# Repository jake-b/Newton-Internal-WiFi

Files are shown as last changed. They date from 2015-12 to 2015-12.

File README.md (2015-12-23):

# Newton-Internal-WiFi
Design and software for a WiFi board for the Apple Newton MessagePad 2x00

- The PCB design for the board (v1.1)
- The Newton PKG software module for enabling the board in software
- STL files for 3D printing a replacement modem port cover. The original
  port cover interferes with the installed PCB.  I have also included a
  representation of the original port cover, in case you need one.  There
  is a version with supports for printing on a typical hobbiest 
  fused-filament 3D printer.  Trim carefully to size using a razor blade.

# Bill of Materials

- PCB fabricated to 0.8mm thickness
- IW-SMG2SMT-EX - Wireach WiFi / 802.11 Module - External Antenna
- JAE IL-WX-32PB-VF-BE - Internal Connector - No longer available
- LMZ21700SILT - Voltage Regulator Module
- R1 SMD 0603 15k Resistor
- Cout SMD 0805 22uF Capacitor
- Cin, C3 SMD 0805 10uF Capacitor
- Css SMD 0603 3.3nF Capacitor
- C4 SMD 0805 470nF
- Rt SMD 0603 562K ohm 1% Resistor
- Rb SMD 0603 180Kohm 0.5% Resistor
- MC74VHCT50ADT - Buffer
- MC74VHC1G04DFT2G - 1G Inverter
- Resettable Fuses - PPTC 15V 1206 .500A POLYFUSE

# License & Disclaimer
This project is released under the Attribution-NonCommercial-ShareAlike 4.0 
International license.

- Feel free to make your own, or make one for your friends.
- Please release any improvements back to the community.
- Non-commerical use only. Please don't make & sell these at a profit.  If
  by some odd chance you want to make these for sale, please contact me.

As with all of my projects, please use this at your own risk.

BECAUSE THE PROGRAM & HARDWARE DESIGN IS LICENSED FREE OF CHARGE, THERE IS NO 
WARRANTY FOR THE PROGRAM & HARDWARE DESIGN, TO THE EXTENT PERMITTED BY 
APPLICABLE LAW. EXCEPT WHEN OTHERWISE STATED IN WRITING THE COPYRIGHT HOLDERS 
AND/OR OTHER PARTIES PROVIDE THE PROGRAM & HARDWARE DESIGN "AS IS" WITHOUT 
WARRANTY OF ANY KIND, EITHER EXPRESSED OR IMPLIED, INCLUDING, BUT NOT LIMITED 
TO, THE IMPLIED WARRANTIES OF MERCHANTABILITY AND FITNESS FOR A PARTICULAR 
PURPOSE. THE ENTIRE RISK AS TO THE QUALITY AND PERFORMANCE OF THE PROGRAM &
HARDWARE DESIGN IS WITH YOU. SHOULD THE PROGRAM OR HARDWARE DESIGN PROVE 
DEFECTIVE, YOU ASSUME THE COST OF ALL NECESSARY SERVICING, REPAIR OR CORRECTION.

IN NO EVENT UNLESS REQUIRED BY APPLICABLE LAW OR AGREED TO IN WRITING WILL ANY
COPYRIGHT HOLDER, OR ANY OTHER PARTY WHO MAY MODIFY AND/OR REDISTRIBUTE THE 
PROGRAM OR HARDWARE DESIGN AS PERMITTED ABOVE, BE LIABLE TO YOU FOR DAMAGES, 
INCLUDING ANY GENERAL,  SPECIAL, INCIDENTAL OR CONSEQUENTIAL DAMAGES ARISING 
OUT OF THE USE OR INABILITY TO USE THE PROGRAM OR HARDWARE DESIGN (INCLUDING 
BUT NOT LIMITED TO LOSS OF DATA OR DATA BEING RENDERED INACCURATE OR LOSSES 
SUSTAINED BY YOU OR THIRD PARTIES OR A FAILURE OF THE PROGRAM OR HARDWARE 
DESIGN TO OPERATE WITH ANY OTHER PROGRAMS OR HARDWARE), EVEN IF SUCH HOLDER 
OR OTHER PARTY HAS BEEN ADVISED OF THE POSSIBILITY OF SUCH DAMAGES.

The software included toggles low level hardware signals using undocumented 
Newton ROM functions. It is intended for developer use. You should know what 
you're doing, as this could do damage to your hardware.

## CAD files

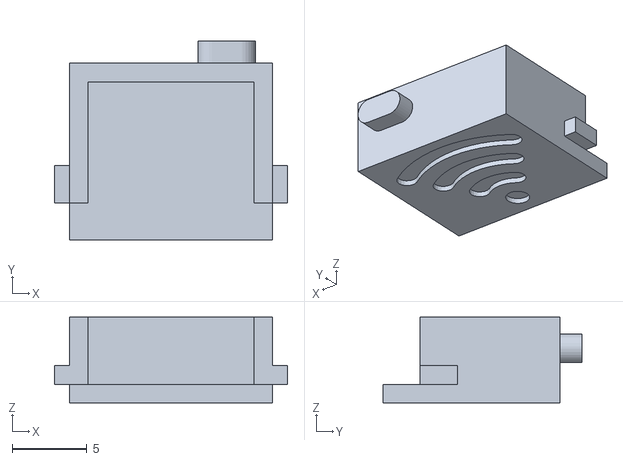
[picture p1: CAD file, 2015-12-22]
Port Cover/Wifi Modem Port Cover.stl
15.6 x 13.4 x 5.75

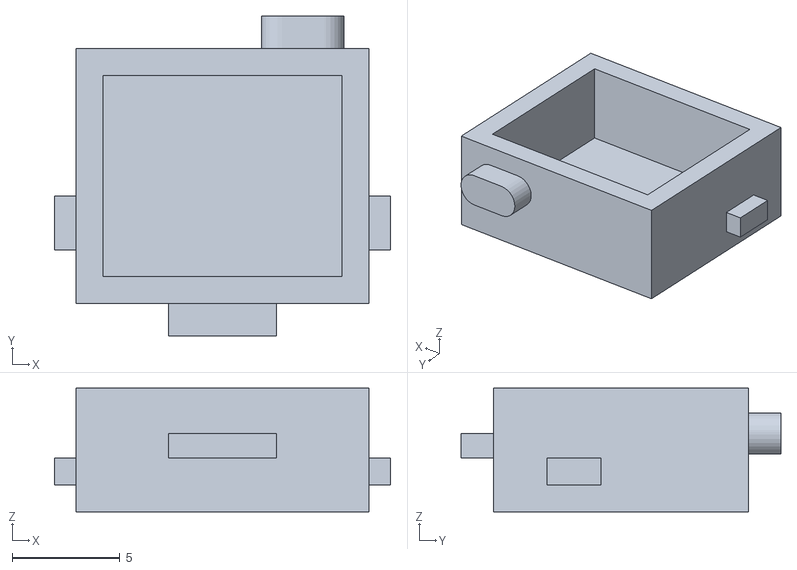
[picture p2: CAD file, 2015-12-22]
Port Cover/Original Modem Port Cover.stl
15.6 x 14.9 x 5.75

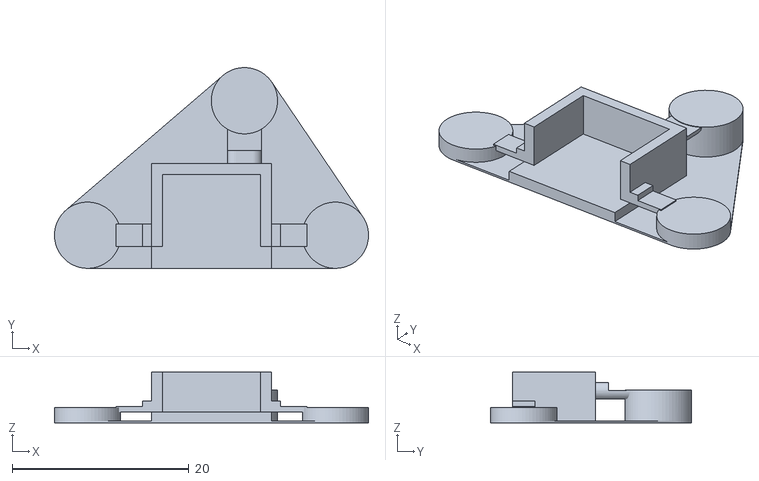
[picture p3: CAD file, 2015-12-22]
Port Cover/Wifi Modem Port Cover - Supported.stl
35.5 x 22.7 x 5.75

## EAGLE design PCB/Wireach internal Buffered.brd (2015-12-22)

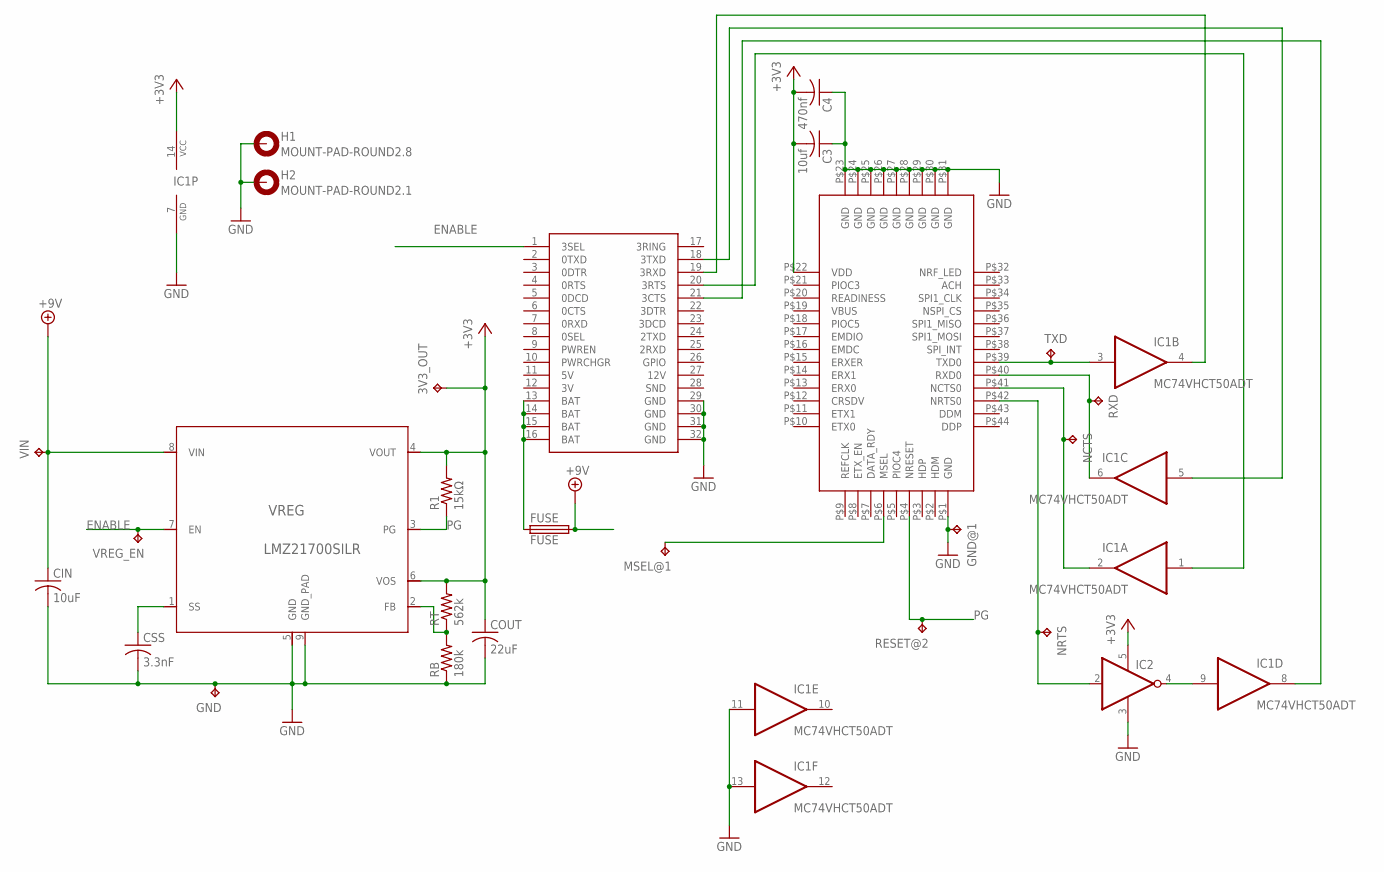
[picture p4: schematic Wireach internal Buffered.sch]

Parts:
3V3_OUT: TPTP10R; TP10R
C3: 10uf; C0805
C4: 470nf; C0805
CIN: 10uF; C0805K
COUT: 22uF; C0805K
CSS: 3.3nF; C0603K
FUSE: FUSE; R1206
GND: TPTP10R; TP10R
GND@1: TPTP10R; TP10R
H1: MOUNT-PAD-ROUND2.8; 2,8-PAD
H2: MOUNT-PAD-ROUND2.1; 2,1-PAD
IC1: MC74VHCT50ADT; TSSOP14
IC2: 1G04-DC; SOT353/5
MSEL@1: TPTP10R; TP10R
NCTS: TPTP10R; TP10R
NRTS: TPTP10R; TP10R
R1: 15kΩ; R0603
RB: 180k; R0603
RESET@2: TPTP10R; TP10R
RT: 562k; R0603
RXD: TPTP10R; TP10R
TXD: TPTP10R; TP10R
U$1: WIREACH
U$3: N2-INTOLD; NEWTON
VIN: TPTP10R; TP10R
VREG: LMZ21700SILR; SIL0008B
VREG_EN: TPTP10R; TP10R

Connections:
+3V3: 3V3_OUT.TP, C3.2, C4.2, COUT.1, IC1.14 (VCC), IC2.5 (VDD), R1.2, RT.2, U$1.P$22 (VDD), VREG.4 (VOUT), VREG.6 (VOS)
+9V: CIN.1, FUSE.2, VIN.TP, VREG.8 (VIN)
ENABLE: U$3.1 (3SEL), VREG.7 (EN), VREG_EN.TP
GND: C3.1, C4.1, CIN.2, COUT.2, CSS.2, GND.TP, GND@1.TP, H1.B2,8, H2.B2,8, IC1.7 (GND), IC1.11 (I), IC1.13 (I), IC2.3 (GND), RB.1, U$1.P$1 (GND), U$1.P$23 (GND), U$1.P$24 (GND), U$1.P$25 (GND), U$1.P$26 (GND), U$1.P$27 (GND), U$1.P$28 (GND), U$1.P$29 (GND), U$1.P$30 (GND), U$1.P$31 (GND), U$3.29 (GND), U$3.30 (GND), U$3.31 (GND), U$3.32 (GND), VREG.5 (GND), VREG.9 (GND_PAD)
unnamed: RB.2, RT.1, VREG.2 (FB)
unnamed: CSS.1, VREG.1 (SS)
unnamed: IC1.9 (I), IC2.4 (O)
unnamed: IC1.3 (I), TXD.TP, U$1.P$39 (TXD0)
unnamed: IC2.2 (I), NRTS.TP, U$1.P$42 (NRTS0)
unnamed: FUSE.1, U$3.13 (BAT), U$3.14 (BAT), U$3.15 (BAT), U$3.16 (BAT)
unnamed: IC1.6 (O), RXD.TP, U$1.P$40 (RXD0)
unnamed: IC1.2 (O), NCTS.TP, U$1.P$41 (NCTS0)
unnamed: MSEL@1.TP, U$1.P$6 (MSEL)
NCTS: IC1.1 (I), U$3.20 (3RTS)
NRTS: IC1.8 (O), U$3.21 (3CTS)
PG: R1.1, RESET@2.TP, U$1.P$4 (NRESET), VREG.3 (PG)
RXD: IC1.5 (I), U$3.18 (3TXD)
TXD: IC1.4 (O), U$3.19 (3RXD)

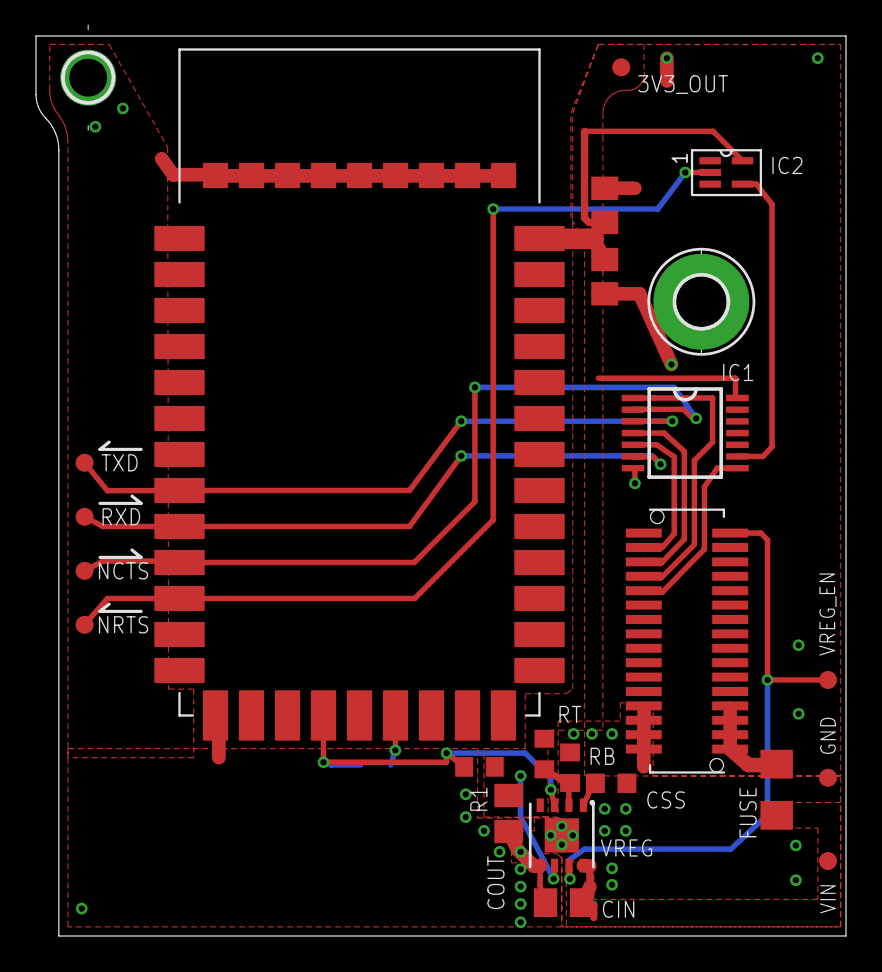
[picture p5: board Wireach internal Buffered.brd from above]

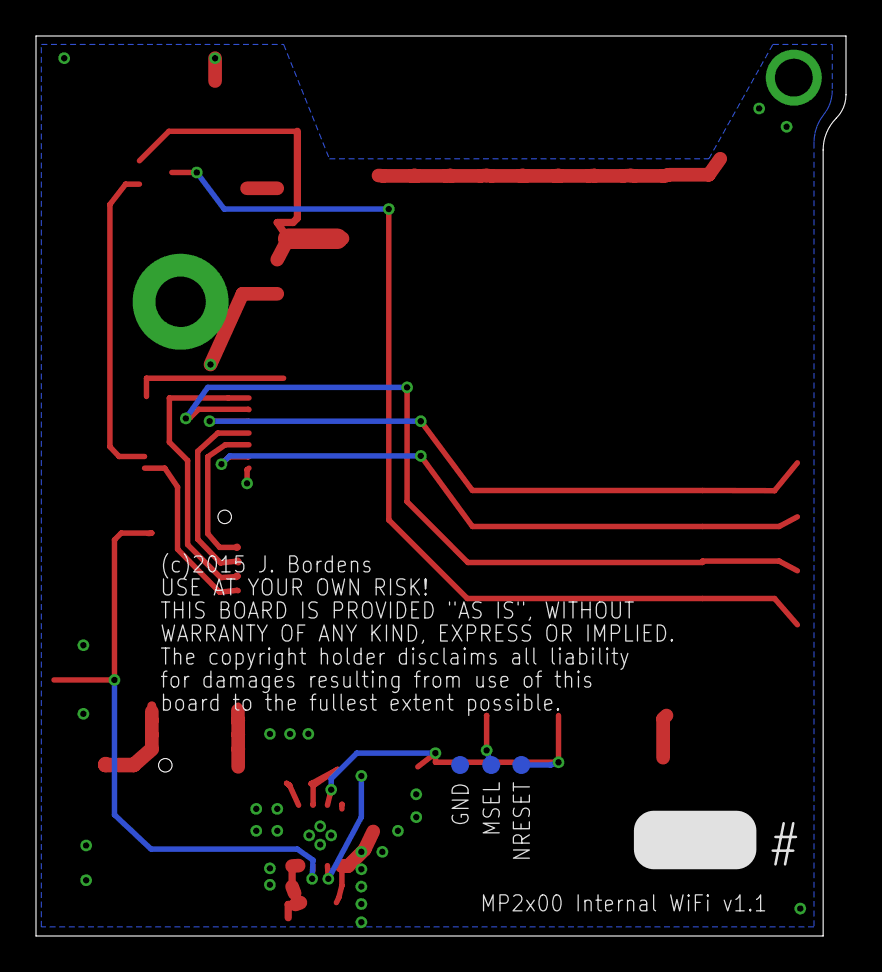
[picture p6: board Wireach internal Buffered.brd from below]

Board: 2 copper layers, 45.0 x 50.0 mm, 27 parts (3 on the bottom side), 18 nets.

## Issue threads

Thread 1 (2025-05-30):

Great! Now I want this too: do you maybe have spare parts you could sell to me?

larsimmisch, 2025-05-30:
Hi,

First of all: great idea and execution. This is probably more future-proof than using a old PCMCIA card.

I've recently discovered that my MP2100 *does* turn on and that I might be able to replace the battery and the aging backlight. I'd love a working WIFI connection, too.

I could get your PCBs printed, but that Internal Connector JAE IL-WX-32PB-VF-BE is, like, unobtainium. Do you maybe have a spare connector you could sell to me and send it to Germany? Any other parts that you could send me would also be great - 10 years is a long time and even the Wireach WiFi might be hard/impossible to get in small quantities.

I know it's asking much, but I'd be really grateful.

My email is mailto:lars@ibp.de

larsimmisch, 2025-05-30:
Cool, thank you! I'll join the mailing list and see if someone is willing to send one to me. If I don't have success there, I'll ask again for the SAMTEC part number.

> I did do some experimentation with an ESP32 but never had the software for the ESP32 that would emulate a PPP server and proxy to a connected wifi access point.

I'll look around some. I'd rather not have to port a PPP server to the ESP32. Or I could wait a few years until the raspberry pis are small enough (only half joking).

I'll close this issue in any case, it's a beg, not an issue, after all.

larsimmisch, 2025-05-31:
Regarding ppp on an ESP32: maybe this could work: https://github.com/jimmyw/esp-idf-ppp-server

Closed 2025-05-30.

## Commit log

2015-12-22 The PCB Design, Sofware Package, and 3D models for an interna Newton WiFi board.
    [Original Modem Port Cover.stl, Wifi Modem Port Cover - Supported.stl, Wifi Modem Port Cover.stl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]
2015-12-22 Added Bill of Materials to README
2015-12-22 fixes to BoM
2015-12-23 Added PCB thickness info.

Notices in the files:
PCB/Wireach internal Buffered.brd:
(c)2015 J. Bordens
